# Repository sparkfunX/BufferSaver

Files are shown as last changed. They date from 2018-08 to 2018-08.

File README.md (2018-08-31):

SparkX SPI Buffer Saver
========================================

SPI Buffer Saver

[*SPI Buffer Saver (SPX-14973)*](https://www.sparkfun.com/products/14973)

The SPI Buffer Saver increases the speed at which you can refresh SPI data without having to modify the Arduino core libraries. It works by rerouting the MOSI channel onto the MISO channel when the chip select pin is active using a tri-state buffer.
The same method can be used to switch other signals so take a peek at the schematic and try it out yourself!

SparkFun labored with love to create this code. Feel like supporting open source hardware? 
Buy a [board](https://www.sparkfun.com/products/14973) from SparkFun!

Repository Contents
-------------------

* **/Documents** - Datasheets
* **/Hardware** - Eagle design files (.brd, .sch)

Library
--------------
* **[Arduino Library](https://github.com/sparkfun/SparkFun_LPS25HB_Arduino_Library)** - Library for reading pressure and changing sensor settings

License Information
-------------------

This product is _**open source**_! 

If you have any questions or concerns on licensing, please contact techsupport@sparkfun.com.

Please use, reuse, and modify these files as you see fit. Please maintain attribution to SparkFun Electronics and release any derivative under the same license.

Distributed as-is; no warranty is given.

- Your friends at SparkFun.

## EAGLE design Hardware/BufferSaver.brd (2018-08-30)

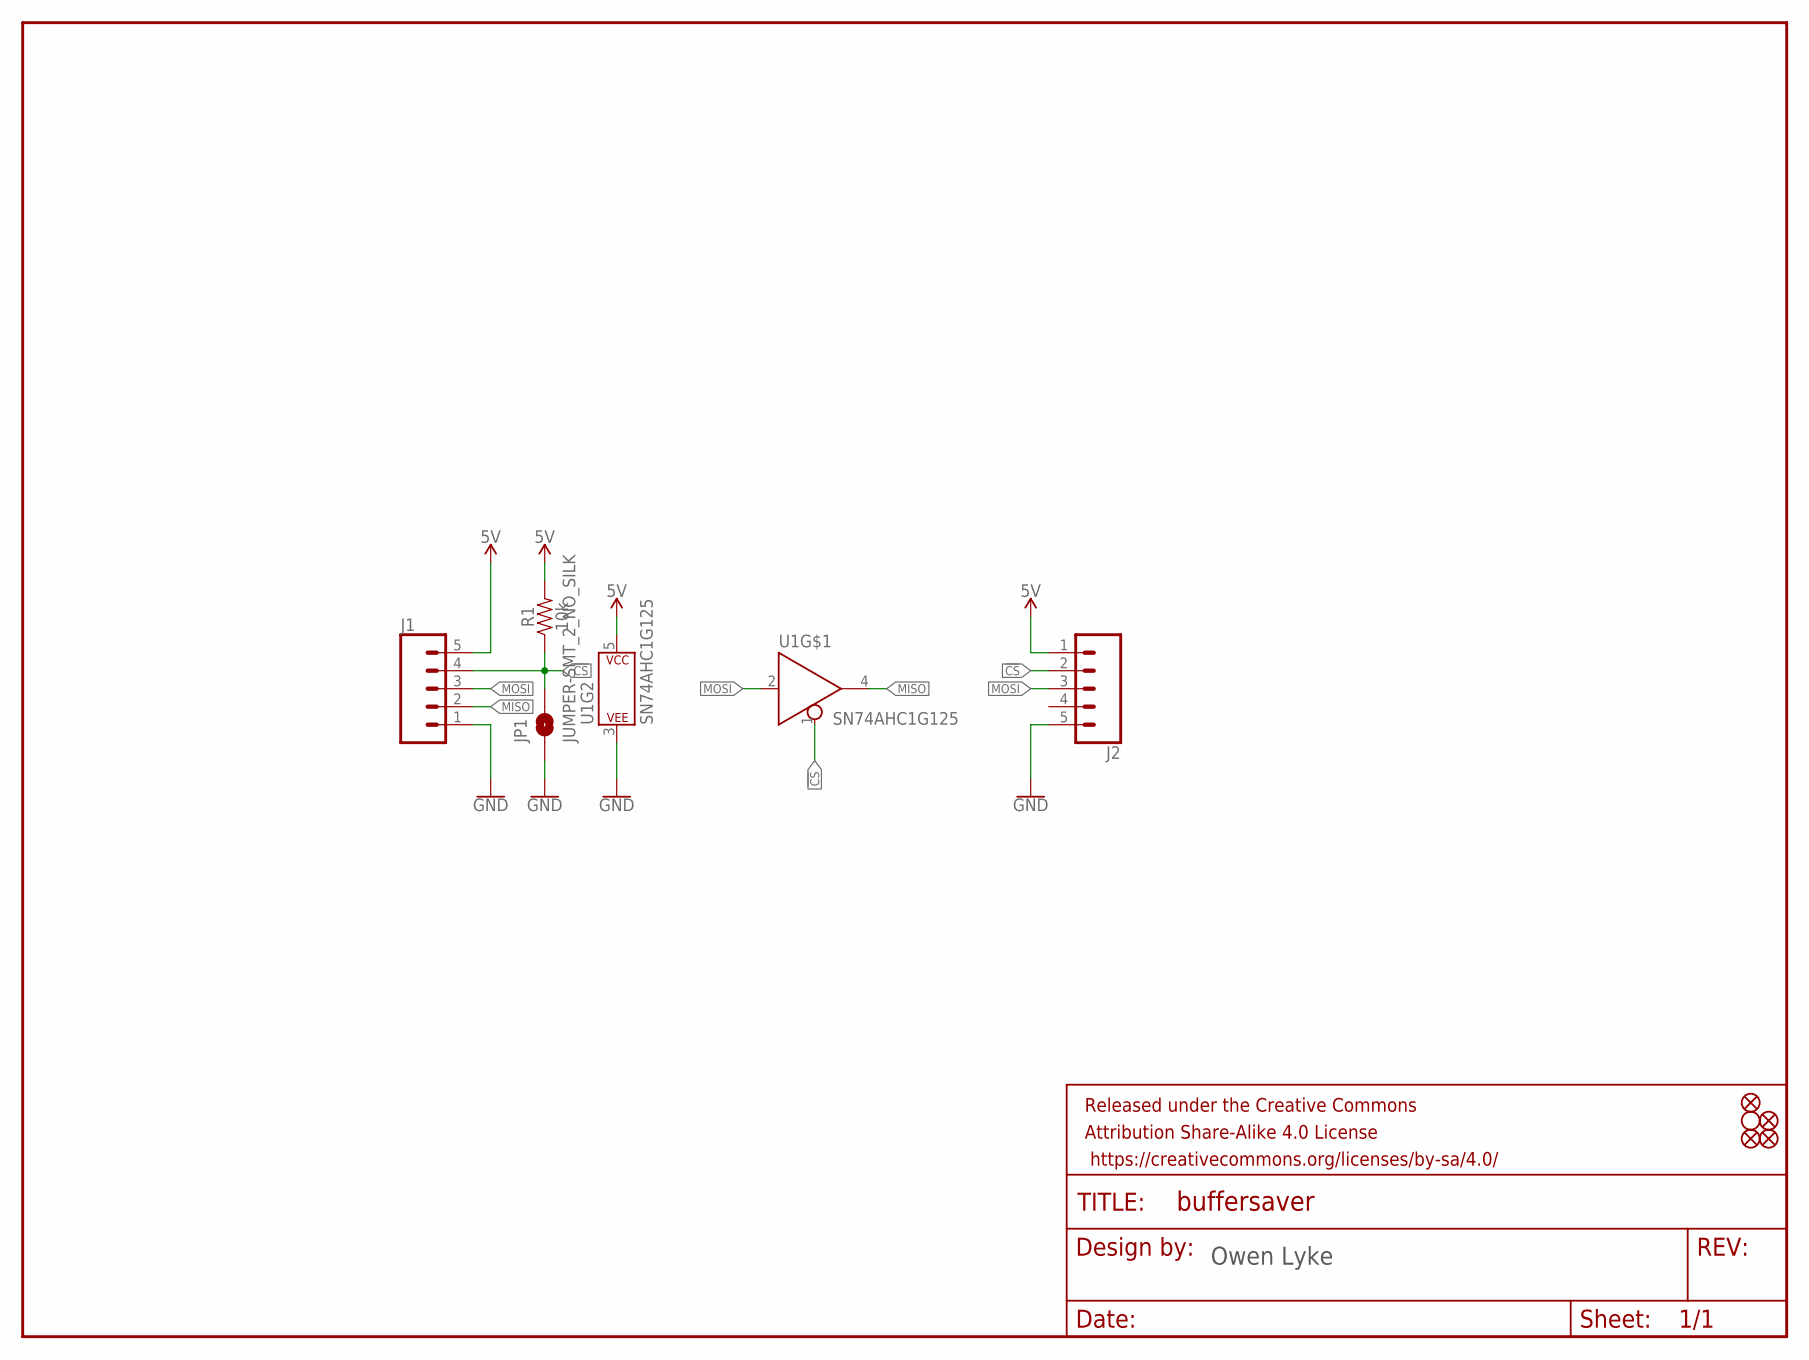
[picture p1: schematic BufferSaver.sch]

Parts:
FD1, FD2, FD3, FD4: FIDUCIAL1X2; FIDUCIAL-1X2
FRAME1: FRAME-LETTER; CREATIVE_COMMONS
H2: STAND-OFF
J1, J2: CONN_05NO_SILK; 1X05_NO_SILK
JP1: JUMPER-SMT_2_NO_SILK; SMT-JUMPER_2_NO_SILK
R1: 10k; 0603
U1: SN74AHC1G125; SOT23-5

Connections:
5V: J1.5, J2.1, R1.2, U1.5 (P$V+)
!CS: J1.4, J2.2, JP1.2, R1.1, U1.1 (!EN)
GND: J1.1, J2.5, JP1.1, U1.3 (P$V-)
MISO: J1.2, U1.4 (Y)
MOSI: J1.3, J2.3, U1.2 (A)

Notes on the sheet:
Owen Lyke

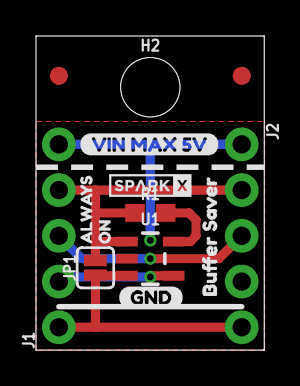
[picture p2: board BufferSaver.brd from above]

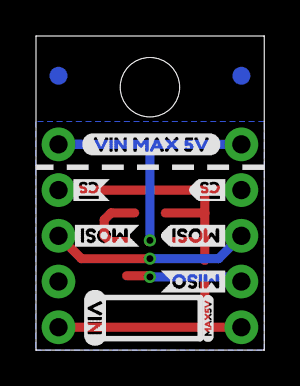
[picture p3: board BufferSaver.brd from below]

Board: 2 copper layers, 12.7 x 17.4 mm, 25 parts (10 on the bottom side), 5 nets.

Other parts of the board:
U$1: #CS3
U$2: #CS4
U$3, U$14: VIN_MAX_5V11
U$4: BUFFER_SAVER7
U$5: GND5
U$6: MISO2
U$7: MAX5V8
U$8: MOSI0
U$10: MOSI1
U$11: ALWAYS9
U$12: VIN6
U$13: ON10
U$34: SPARKX-LOGO2; SPARKX-TINY

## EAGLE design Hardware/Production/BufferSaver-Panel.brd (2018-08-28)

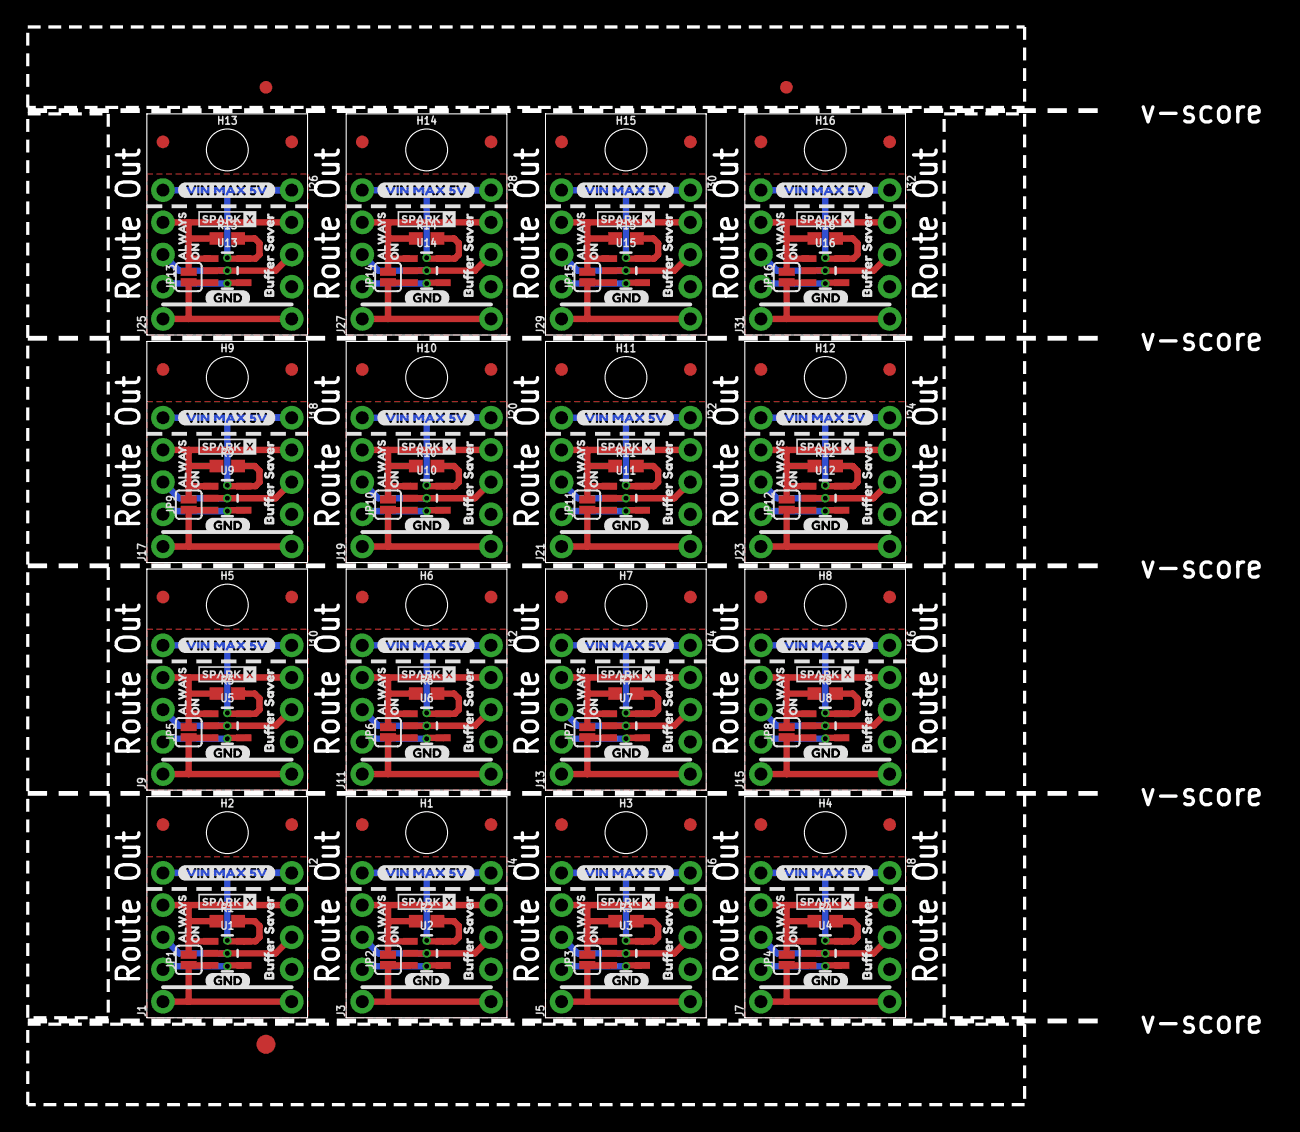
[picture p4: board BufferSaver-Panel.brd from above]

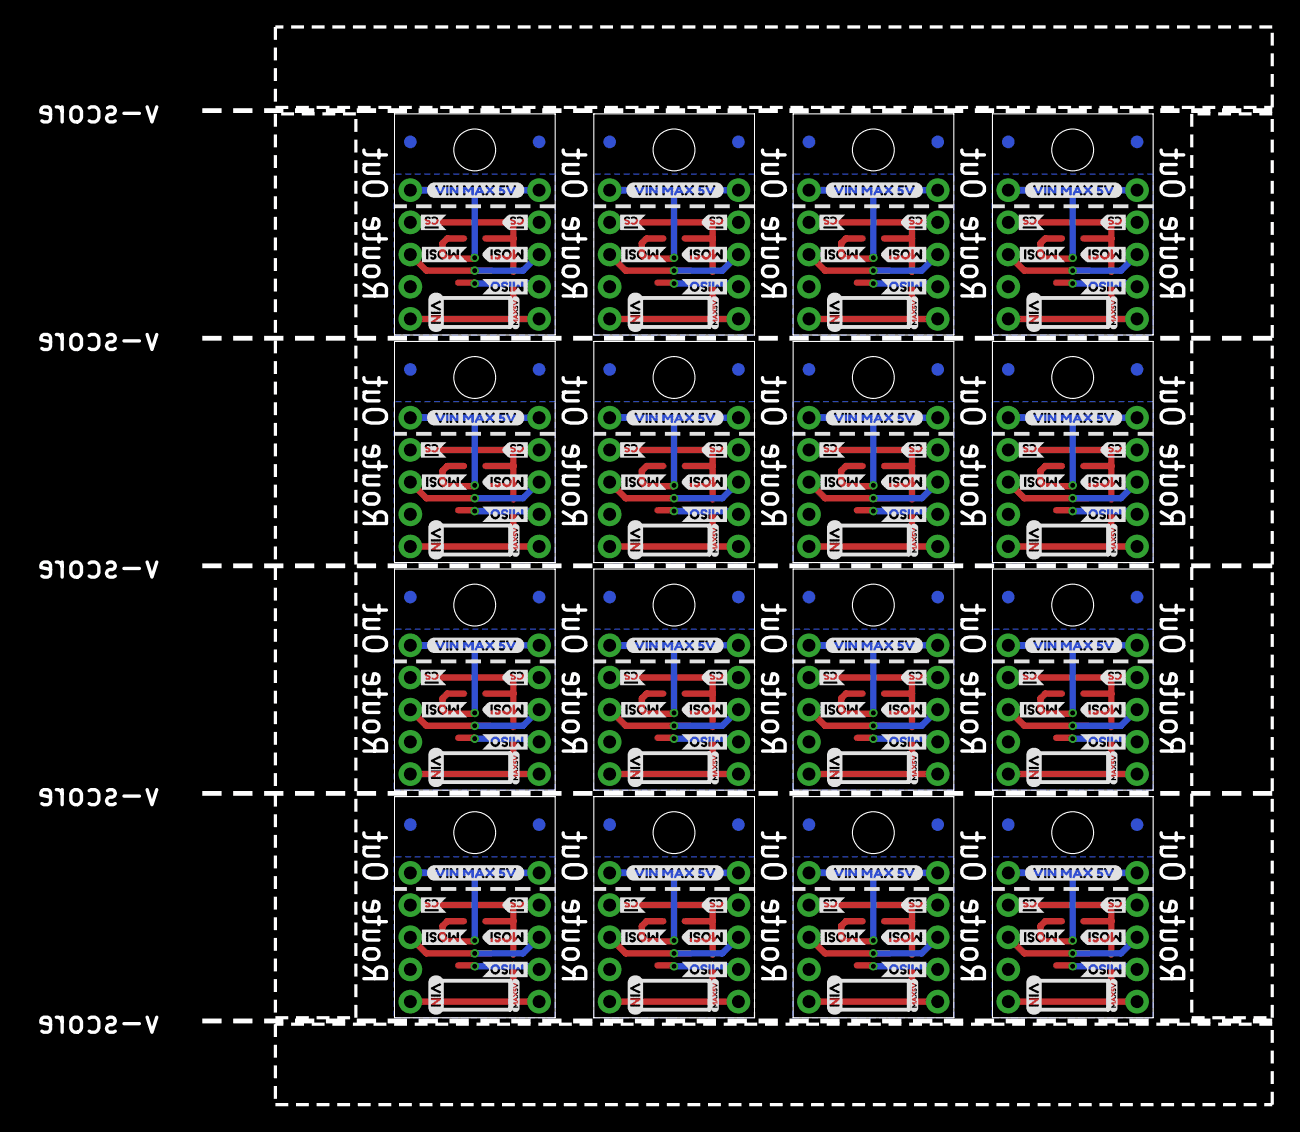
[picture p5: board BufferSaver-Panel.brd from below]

Board: 2 copper layers, 85.0 x 85.0 mm, 387 parts (160 on the bottom side), 80 nets.

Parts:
E$1, E$2: FIDUCIAL-1X2
E$3: FIDUCIAL-1.5X3
FD1, FD2, FD3, FD4, FD5, FD6, FD7, FD8, FD9, FD10, FD11, FD12, FD13, FD14, FD15, FD16, FD17, FD18, FD19, FD20, FD21, FD22, FD23, FD24, FD25, FD26, FD27, FD28, FD29, FD30, FD31, FD32, FD33, FD34, FD35, FD36, FD37, FD38, FD39, FD40, FD41, FD42, FD43, FD44, FD45, FD46, FD47, FD48, FD49, FD50, FD51, FD52, FD53, FD54, FD55, FD56, FD57, FD58, FD59, FD60, FD61, FD62, FD63, FD64: FIDUCIAL1X2; FIDUCIAL-1X2
H1, H2, H3, H4, H5, H6, H7, H8, H9, H10, H11, H12, H13, H14, H15, H16: STAND-OFF
J1, J2, J3, J4, J5, J6, J7, J8, J9, J10, J11, J12, J13, J14, J15, J16, J17, J18, J19, J20, J21, J22, J23, J24, J25, J26, J27, J28, J29, J30, J31, J32: 1X05_NO_SILK
JP1, JP2, JP3, JP4, JP5, JP6, JP7, JP8, JP9, JP10, JP11, JP12, JP13, JP14, JP15, JP16: JUMPER-SMT_2_NO_SILK; SMT-JUMPER_2_NO_SILK
R1, R2, R3, R4, R5, R6, R7, R8, R9, R10, R11, R12, R13, R14, R15, R16: 10k; 0603
U1, U2, U3, U4, U5, U6, U7, U8, U9, U10, U11, U12, U13, U14, U15, U16: SN74AHC1G125; SOT23-5
U$1, U$9, U$28, U$43, U$57, U$71, U$85, U$99, U$113, U$127, U$141, U$155, U$169, U$183, U$197, U$211: #CS3
U$2, U$20, U$35, U$49, U$63, U$77, U$91, U$105, U$119, U$133, U$147, U$161, U$175, U$189, U$203, U$217: #CS4
U$3, U$14, U$26, U$27, U$41, U$42, U$55, U$56, U$69, U$70, U$83, U$84, U$97, U$98, U$111, U$112, U$125, U$126, U$139, U$140, U$153, U$154, U$167, U$168, U$181, U$182, U$195, U$196, U$209, U$210, U$223, U$224: VIN_MAX_5V11
U$4, U$22, U$37, U$51, U$65, U$79, U$93, U$107, U$121, U$135, U$149, U$163, U$177, U$191, U$205, U$219: BUFFER_SAVER7
U$5, U$15, U$29, U$44, U$58, U$72, U$86, U$100, U$114, U$128, U$142, U$156, U$170, U$184, U$198, U$212: GND5
U$6, U$16, U$30, U$45, U$59, U$73, U$87, U$101, U$115, U$129, U$143, U$157, U$171, U$185, U$199, U$213: MISO2
U$7, U$23, U$38, U$52, U$66, U$80, U$94, U$108, U$122, U$136, U$150, U$164, U$178, U$192, U$206, U$220: MAX5V8
U$8, U$19, U$33, U$48, U$62, U$76, U$90, U$104, U$118, U$132, U$146, U$160, U$174, U$188, U$202, U$216: MOSI0
U$10, U$17, U$31, U$46, U$60, U$74, U$88, U$102, U$116, U$130, U$144, U$158, U$172, U$186, U$200, U$214: MOSI1
U$11, U$24, U$39, U$53, U$67, U$81, U$95, U$109, U$123, U$137, U$151, U$165, U$179, U$193, U$207, U$221: ALWAYS9
U$12, U$18, U$32, U$47, U$61, U$75, U$89, U$103, U$117, U$131, U$145, U$159, U$173, U$187, U$201, U$215: VIN6
U$13, U$25, U$40, U$54, U$68, U$82, U$96, U$110, U$124, U$138, U$152, U$166, U$180, U$194, U$208, U$222: ON10
U$21, U$34, U$36, U$50, U$64, U$78, U$92, U$106, U$120, U$134, U$148, U$162, U$176, U$190, U$204, U$218: SPARKX-LOGO2; SPARKX-TINY

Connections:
5V: J1.5, J2.1, R1.2, U1.5
5V1: J3.5, J4.1, R2.2, U2.5
5V2: J5.5, J6.1, R3.2, U3.5
5V3: J7.5, J8.1, R4.2, U4.5
5V4: J9.5, J10.1, R5.2, U5.5
5V5: J11.5, J12.1, R6.2, U6.5
5V6: J13.5, J14.1, R7.2, U7.5
5V7: J15.5, J16.1, R8.2, U8.5
5V8: J17.5, J18.1, R9.2, U9.5
5V9: J19.5, J20.1, R10.2, U10.5
5V10: J21.5, J22.1, R11.2, U11.5
5V11: J23.5, J24.1, R12.2, U12.5
5V12: J25.5, J26.1, R13.2, U13.5
5V13: J27.5, J28.1, R14.2, U14.5
5V14: J29.5, J30.1, R15.2, U15.5
5V15: J31.5, J32.1, R16.2, U16.5
!CS: J1.4, J2.2, JP1.2, R1.1, U1.1
!CS1: J3.4, J4.2, JP2.2, R2.1, U2.1
!CS2: J5.4, J6.2, JP3.2, R3.1, U3.1
!CS3: J7.4, J8.2, JP4.2, R4.1, U4.1
!CS4: J9.4, J10.2, JP5.2, R5.1, U5.1
!CS5: J11.4, J12.2, JP6.2, R6.1, U6.1
!CS6: J13.4, J14.2, JP7.2, R7.1, U7.1
!CS7: J15.4, J16.2, JP8.2, R8.1, U8.1
!CS8: J17.4, J18.2, JP9.2, R9.1, U9.1
!CS9: J19.4, J20.2, JP10.2, R10.1, U10.1
!CS10: J21.4, J22.2, JP11.2, R11.1, U11.1
!CS11: J23.4, J24.2, JP12.2, R12.1, U12.1
!CS12: J25.4, J26.2, JP13.2, R13.1, U13.1
!CS13: J27.4, J28.2, JP14.2, R14.1, U14.1
!CS14: J29.4, J30.2, JP15.2, R15.1, U15.1
!CS15: J31.4, J32.2, JP16.2, R16.1, U16.1
GND: J1.1, J2.5, JP1.1, U1.3
GND1: J3.1, J4.5, JP2.1, U2.3
GND2: J5.1, J6.5, JP3.1, U3.3
GND3: J7.1, J8.5, JP4.1, U4.3
GND4: J9.1, J10.5, JP5.1, U5.3
GND5: J11.1, J12.5, JP6.1, U6.3
GND6: J13.1, J14.5, JP7.1, U7.3
GND7: J15.1, J16.5, JP8.1, U8.3
GND8: J17.1, J18.5, JP9.1, U9.3
GND9: J19.1, J20.5, JP10.1, U10.3
GND10: J21.1, J22.5, JP11.1, U11.3
GND11: J23.1, J24.5, JP12.1, U12.3
GND12: J25.1, J26.5, JP13.1, U13.3
GND13: J27.1, J28.5, JP14.1, U14.3
GND14: J29.1, J30.5, JP15.1, U15.3
GND15: J31.1, J32.5, JP16.1, U16.3
MISO: J1.2, U1.4
MISO1: J3.2, U2.4
MISO2: J5.2, U3.4
MISO3: J7.2, U4.4
MISO4: J9.2, U5.4
MISO5: J11.2, U6.4
MISO6: J13.2, U7.4
MISO7: J15.2, U8.4
MISO8: J17.2, U9.4
MISO9: J19.2, U10.4
MISO10: J21.2, U11.4
MISO11: J23.2, U12.4
MISO12: J25.2, U13.4
MISO13: J27.2, U14.4
MISO14: J29.2, U15.4
MISO15: J31.2, U16.4
MOSI: J1.3, J2.3, U1.2
MOSI1: J3.3, J4.3, U2.2
MOSI2: J5.3, J6.3, U3.2
MOSI3: J7.3, J8.3, U4.2
MOSI4: J9.3, J10.3, U5.2
MOSI5: J11.3, J12.3, U6.2
MOSI6: J13.3, J14.3, U7.2
MOSI7: J15.3, J16.3, U8.2
MOSI8: J17.3, J18.3, U9.2
MOSI9: J19.3, J20.3, U10.2
MOSI10: J21.3, J22.3, U11.2
MOSI11: J23.3, J24.3, U12.2
MOSI12: J25.3, J26.3, U13.2
MOSI13: J27.3, J28.3, U14.2
MOSI14: J29.3, J30.3, U15.2
MOSI15: J31.3, J32.3, U16.2

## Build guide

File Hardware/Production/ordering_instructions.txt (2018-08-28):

panel size, 79x86mm
PCB thickness, 1.6mm
number of layers, 2
soldermask color, Black
silkscreen color, White
oz copper, 1oz
finish, HASL lead free
stencils, top+bottom
pcs per panel, 16

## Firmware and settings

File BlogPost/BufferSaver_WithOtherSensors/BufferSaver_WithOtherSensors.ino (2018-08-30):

/*
 * Owen Lyke
 * August 2018
 * 
 * Of course you don't always want MOSI connected to MISO - that would prevent you from talking to other sensors!
 * That's why I included a CS pin for the buffer saver. When the CS pin is high the tri-state buffer is disabled.
 * This keeps the SPI bus available for other sensors! (But you can't add more LED strips cause they would need 
 * their own CS pin to receive unique data. Hey... there's an idea!)
 * 
 * Free code! As long as it doesn't hurt anyone you can do with it whatever you like.
 */
#include "SparkFunLIS3DH.h"
#include "SPI.h"

LIS3DH SensorOne( SPI_MODE, 1 );

#define BRIGHTNESS 10 /* valid [0, 31] */
#define NUM_LEDS 9
uint8_t data[4*(NUM_LEDS + 2)];

#define BS_CS_PIN 0
#define SENSOR_CS_PIN 1

uint16_t count = 0;
uint8_t ledCount = NUM_LEDS - 1;

//SPISettings mySPIsettings(10000000, MSBFIRST, SPI_MODE3);
SPISettings mySPIsettings(10000000, MSBFIRST, SPI_MODE3);      // Slower test for my Logic4

void setup() {
  SPI.begin();
  kickSPI();
  Serial.begin(9600);
  while(!Serial){};

  pinMode(BS_CS_PIN, OUTPUT);
  digitalWrite(BS_CS_PIN, HIGH);

  //Call .begin() to configure the IMUs
  uint8_t returnData = 0;
  returnData = SensorOne.begin();
  if(( returnData != 0x00 )&&( returnData != 0xFF ))
  {
    Serial.println("Problem starting the sensor with CS @ Pin 10.");
  }
  else
  {
    Serial.println("Sensor with CS @ Pin 10 started.");
  }

  Serial.println("BufferSaver with Other Sensors");
  Serial.println();
  
  Serial.println("- Connect an APA102 LED strip to the SPI port on your microcontroller");
  Serial.println("- Use a BufferSaver board with the CS pin connected to pin 0");
  Serial.println("- Add another SPI sensor with the CS pin connected to pin 1");

  Serial.println();
  Serial.println("If the CS pin on the buffer saver is high then the other sensor is");
  Serial.println("allowed to control the MISO line");

  setupData();  // Initialize the data that you want to send out

  // Now set up a few LEDs the way you like using the setLED function. The first led is led0, then led1 and so on. led(NUM_LEDS-1) is the last led
  // setLED(uint16_t led, uint8_t r, uint8_t g, uint8_t b)
  setLED(3, 255, 0, 0);
  setLED(4, 0, 255, 0);
  setLED(5, 0, 0, 255);

  // Then we send out the data once and enjoy the masterpeice
  sendData();
  delay(1000); // Time to read the message and see that your initial data send worked OK
}

void loop() {
  // Now we will want to change the LED data  to make an animation of sorts

  delay(16);    // 60 Hz refresh... (ish - not accounting for other operations)
//  Serial.println(millis());

  // Once per second advance the LED
  if(++count > 60)
  {
    count = 0;
    setLED(ledCount, 0, 0, 0);      // Reset the current LED
    if(++ledCount > NUM_LEDS - 1)   // Increment the current LED
    {
      ledCount = 0; 
    }
    setLED(ledCount, 255, 0, 0);    // Set the current LED (after increment)
  }

  if(!(count % 10))
  {
    printAccData();
  }
  
  sendData();   // So, when you send the data with SPI.transfer() the data array will be overwritten and you can't be sure what will come out next!
}

void setupData( void )
{
  data[0] = 0x00;                     // 4 bytes of all zeros signals 
  data[1] = 0x00;                     // a new data stream to the leds
  data[2] = 0x00;
  data[3] = 0x00;
  for(uint16_t indi = 0; indi < NUM_LEDS; indi++)
  {
    // Here's where the actual LED data exists - 4 bytes for each led
    data[(4* indi) + 0] = (0xE0 | (0x1F & BRIGHTNESS)); // Brightness has a special format of 0b111BBBBB 
    data[(4* indi) + 1] = 0x00; // Blue
    data[(4* indi) + 2] = 0x00; // Green
    data[(4* indi) + 3] = 0x00; // Red
  }
  data[(4* NUM_LEDS) + 0] = 0xFF;     // The last 4 bytes are all white.
  data[(4* NUM_LEDS) + 1] = 0xFF;     // Not strictly necessary, but it
  data[(4* NUM_LEDS) + 2] = 0xFF;     // helps you know if you have more 
  data[(4* NUM_LEDS) + 3] = 0xFF;     // LEDs available
}

void sendData( void )
{
//  SPI.beginTransaction(SPISettings(1000000, MSBFIRST, SPI_MODE3));
  kickSPI();
  digitalWrite(BS_CS_PIN, LOW);
//  delay(1);
  SPI.beginTransaction(mySPIsettings);

  SPI.transfer(data, 4*(NUM_LEDS+2));
  for(uint16_t indi = 0; indi < NUM_LEDS/2 + 1; indi++)
  {
    SPI.transfer(0x00);  // You need to provide extra clock cycles to APA102
  }
  SPI.endTransaction();
  digitalWrite(BS_CS_PIN, HIGH);
//  delay(1);
}

void setLED(uint16_t led, uint8_t r, uint8_t g, uint8_t b)
{
  if(led >= NUM_LEDS)
  {
    return;
  }
  
  data[4*(led + 1) + 0] = (0xE0 | (0x1F & BRIGHTNESS));
  data[4*(led + 1) + 1] = b;
  data[4*(led + 1) + 2] = g;
  data[4*(led + 1) + 3] = r;
}

void kickSPI( void )
{
  // "Kick" the SPI hardware to start in the correct clock polarity etc
  SPI.beginTransaction(mySPIsettings);
  for(uint8_t indi = 0; indi < 4; indi++)
  {
    SPI.transfer(0x00);  // You need to provide extra clock cycles to APA102
  }
  SPI.endTransaction();
}

void printAccData( void )
{
  //Get all parameters
  Serial.print("\nAccelerometer:\n");
  Serial.print(" X1 = ");
  Serial.println(SensorOne.readFloatAccelX(), 4);
  Serial.print(" Y1 = ");
  Serial.println(SensorOne.readFloatAccelY(), 4);
  Serial.print(" Z1 = ");
  Serial.println(SensorOne.readFloatAccelZ(), 4);
  
  Serial.print("\nSensorOne Bus Errors Reported:\n");
  Serial.print(" All '1's = ");
  Serial.println(SensorOne.allOnesCounter);
  Serial.print(" Non-success = ");
  Serial.println(SensorOne.nonSuccessCounter);
}

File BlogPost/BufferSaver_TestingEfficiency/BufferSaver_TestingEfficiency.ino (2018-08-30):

/*
 * This is a sort of simple benchmark program to see how much the BufferSaver saves you in terms of execution time
 * 
 * Owen Lyke
 * August 2018
 * 
 * Free code! As long as it doesn't hurt anyone you can do with it what you please.
 */

#include "SPI.h"

typedef struct{
  uint16_t numTests;
  uint32_t * p_sizes;
  uint32_t * presults_individual;
  uint32_t * presults_enforce;
  uint32_t * presults_buffer;
}TestParams_TypeDef;


#define NUM_TESTS 10
#define CS 0

SPISettings mySettings(10000000, MSBFIRST, SPI_MODE3);

uint32_t sizes[NUM_TESTS] = {1,5,10,15,25,50,100,250,500,1000};
uint32_t resInd[NUM_TESTS];
uint32_t resEnf[NUM_TESTS];
uint32_t resBuf[NUM_TESTS];


TestParams_TypeDef testSpec;



void setup() {
  // put your setup code here, to run once:
  pinMode(CS, OUTPUT);
  digitalWrite(CS, HIGH);


  testSpec.numTests = NUM_TESTS;
  testSpec.p_sizes = sizes;
  testSpec.presults_individual = resInd;
  testSpec.presults_enforce = resEnf;
  testSpec.presults_buffer = resBuf;

  SPI.begin();

  Serial.begin(9600);
  while(!Serial){};

  Serial.println("Buffer Saver - Testing Efficiency");
  Serial.println("---------------------------------");
  Serial.println("                                 ");
  printTestParameters(&testSpec);

  runFullTest(&testSpec);
  printTestResults(&testSpec);

}

void loop() {
  // put your main code here, to run repeatedly:

}

void runFullTest(TestParams_TypeDef * ptestParams)
{
  for(uint16_t indi = 0; indi < ptestParams->numTests; indi++)
  {
    Serial.print("testing case: "); Serial.println(indi);
    testCase(indi, ptestParams);
  }
  Serial.println("\n");
}

void testCase(uint16_t caseIndex, TestParams_TypeDef * ptestParams)
{
// Allocate the memory to send out
  uint32_t numBytes = *(ptestParams->p_sizes + caseIndex);
  uint8_t * pdata = NULL;
  pdata = (uint8_t *)malloc(numBytes*sizeof(uint8_t));
  if(pdata == NULL)
  {
    abortCase(caseIndex, ptestParams);
    free(pdata);
    return;
  }

  *(ptestParams->presults_individual + caseIndex) =  testIndividualWrites(pdata, numBytes);
  *(ptestParams->presults_enforce + caseIndex) =  testEnforceBuffer(pdata, numBytes);
  *(ptestParams->presults_buffer + caseIndex) =  testBufferSaverMethod(pdata, numBytes);

  // deallocate the memory
  free(pdata);
}

void abortCase(uint16_t caseIndex, TestParams_TypeDef * ptestParams)
{
  // Set results to zero here
  *(ptestParams->presults_individual + caseIndex) = 0;
  *(ptestParams->presults_enforce + caseIndex) = 0;
  *(ptestParams->presults_buffer + caseIndex) = 0;
}

uint32_t testIndividualWrites(uint8_t * pdata, uint32_t size)
{
  // In this test the cost of setting the data is ignored because it is protected by just transferring one byte at a time
  SPI.beginTransaction(mySettings);
  uint32_t tn = micros();
  for(uint32_t indi = 0; indi < size; indi++)
  {
    SPI.transfer(*(pdata + indi)); // Directly transfer from the data buffer one byte at a time. 
  }
  uint32_t tt = micros();
  SPI.endTransaction();
  return (tt-tn);
}

uint32_t testEnforceBuffer(uint8_t * pdata, uint32_t size)
{
  // In this test the time to reset the whole buffer is included because it happens for every output
  SPI.beginTransaction(mySettings);
  volatile uint8_t volvar = 0;
  uint32_t tn = micros();
  for(uint32_t indi = 0; indi < size; indi++)
  {
    *(pdata + indi) = volvar; // Volatile variable used to prevent compiler optimization
  }
  SPI.transfer(pdata, size);
  uint32_t tt = micros();
  SPI.endTransaction();
  return (tt-tn);
}

uint32_t testBufferSaverMethod(uint8_t * pdata, uint32_t size)
{
  SPI.beginTransaction(mySettings);
  uint32_t tn = micros();
  digitalWrite(CS, LOW);      // Worst case scenario you will need to toggle a pin
  SPI.transfer(pdata, size);  // If the buffer saver is used you can just send the data, no worries
  digitalWrite(CS, HIGH);     // And detoggle the pin when you're done
  uint32_t tt = micros();
  SPI.endTransaction();
  return (tt-tn);  
}

void printTestResults(TestParams_TypeDef * ptestParams)
{
  Serial.println("Test Results:");
  Serial.println("-------------");
  Serial.println("");

  Serial.println("Number of bytes, Individual Writes (uS), Pre-enforce (uS), BufferSaver (uS)");
  Serial.println("---------------------------------------------------------------------------");
  for(uint32_t indi = 0; indi < ptestParams->numTests; indi++)
  {
    Serial.print(*(ptestParams->p_sizes + indi)); Serial.print(", ");
    Serial.print(*(ptestParams->presults_individual + indi)); Serial.print(", ");
    Serial.print(*(ptestParams->presults_enforce + indi)); Serial.print(", ");
    Serial.print(*(ptestParams->presults_buffer + indi)); Serial.println("");
  }
}

void printTestParameters(TestParams_TypeDef * ptestParams)
{
  Serial.println("Test Settings (change in setup):");
  Serial.print("Number of cases to run: "); Serial.println(ptestParams->numTests);

  Serial.print("Number of bytes to write in each test: ");
  for(uint32_t indi = 0; indi < ptestParams->numTests; indi++)
  {
    Serial.print(*(ptestParams->p_sizes + indi)); 
    
    if(indi != (ptestParams->numTests - 1))
    {
      Serial.print(", ");
    }
  }
  Serial.println();
}

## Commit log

2018-08-29 Added a second buffer to allow for multiple led strips on one SPI port!
    [BufferSaver.brd, BufferSaver.sch]
2018-08-30 Revert "Added a second buffer to allow for multiple led strips on one SPI port!"
    This reverts commit a22a5d977a95e097da70702a3350ebab49920d41.
    [BufferSaver.brd, BufferSaver.sch]
2018-08-30 Revert "Revert "Added a second buffer to allow for multiple led strips on one SPI port!""
    This reverts commit 93b898f1311a7606d26b6a396d53439853d3f191.
    [BufferSaver.brd, BufferSaver.sch]
2018-08-30 Fixed buffer symbol
    [BufferSaver.brd, BufferSaver.sch]
2018-08-31 Not sure
    [BufferSaver.sch]

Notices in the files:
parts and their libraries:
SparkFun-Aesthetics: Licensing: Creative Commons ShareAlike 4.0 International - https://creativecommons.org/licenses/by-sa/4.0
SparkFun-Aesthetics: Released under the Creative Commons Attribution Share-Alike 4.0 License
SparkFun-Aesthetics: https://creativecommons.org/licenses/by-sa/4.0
